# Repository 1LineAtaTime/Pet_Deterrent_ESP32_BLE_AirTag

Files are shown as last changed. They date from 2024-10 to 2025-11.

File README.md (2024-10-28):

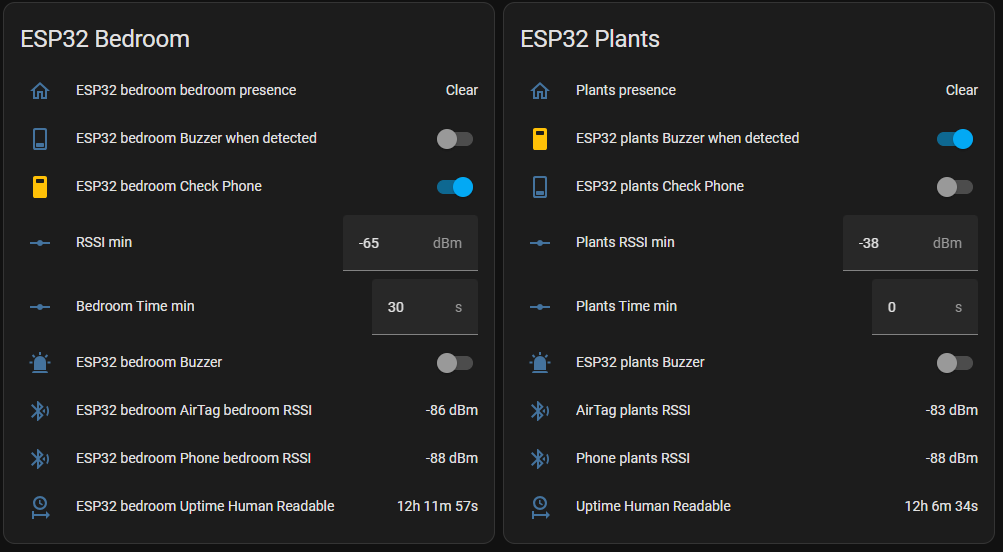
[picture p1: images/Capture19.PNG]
overview


# Introduction

Please note there are 2 different branches in this repo: this one uses ESPhome and Alexa_Media_Player instead to integrate with Home Assistant, Alexa, OTA, monitoring, etc. The other one is standalone with "Sinric Pro" to integrate with Alexa and OTA.

Pet Deterrent by using a Mini ESP32 with BLE scanning, WiFi, Alexa integration and OTA through ESPHome, Home Assistant and Alexa_Media_Player.

This program transforms an ESP32 into an AirTag detector (or any other BLE device) and pushes notifications to a dashboard in Home Assistant, which manages the OTAs and the Alexa integration.

There are a myriad of use cases for this device. I personally created it to know when my cats decide to start eating my plants or go into a room they are not supposed to be in. Both of my cats have an AirTag on their collar, in case one day they escape, so I can get an idea of what neighborhood they could be in. I then use these same air tags to detect if they are nearby. I have a spare iPhone I used to set them up on the Find My network, but then shut it off. The anti-stalker feature of the AirTag makes it advertise its presence every 2 seconds when they've been out of range of the parent phone for a while. Both the Address() and ManufacturerData() of the AirTag changes periodically, but we can extract the first few characters of the ManufacturerData() to identify it. More info on the Advertising Data can be found [here](https://adamcatley.com/AirTag.html).
> [!TIP]
> The anti-stalker feature now also makes the AirTag beep every few hours. I just opened it up and removed the diaphragm that amplifies the sound. There are plenty of videos online on how to do it without breaking your AirTag. While this doesn't completely turn off the sound, it makes the sound not noticeable, which is kind of important if your pet is going to be carrying it all the time. The anti-stalker feature only activates if it doesn't detect your iPhone for X number of hours. I use Android, so my iPhone is stored in a box turned off.

Other cases could be setting a trap door that only gets activated by a specific type of BLE device (e.g. backyard dog trap door), etc.

Since I did not want to have 3 different files to maintain for the 3 ESP32's I have around the house, I have tried to implement everything into one. 
In my case, I have 1 of the ESP32 in the bedroom, which will trigger the alarm if and only if my phone is not detected while the Air Tag is there, but the RSSI value is pretty laxed (-60, which in that room is approximately 6 feet). 
On the other hand, I do not need to check if my phone is nearby for the ESP32 boards I have next to the plants, which also has a pretty tight threshold (-38, about 4 inches away).

```
RAM:   [==        ]  16.5% (used 54216 bytes from 327680 bytes)
Flash: [=======   ]  74.5% (used 1366497 bytes from 1835008 bytes)
```
FYI, I had initially reduced the SPIFFS partition while leaving OTA intact with "board_build.partitions = min_spiffs.csv" in platformio.ini for the other branch, but the initialization of the ESP Home website formats the board differently, I believe.

# Instructions

1. Set up your board as you'd like. This is how mine looks.
    I am using this [Mini ESP32](https://www.aliexpress.us/item/3256806443469796.html), this [buzzer](https://www.ebay.com/itm/126428954898) and [this case](Archives/ESP32_wider_opening_for_USB.stl) with this [cover](Archives/ESP32_Top.stl).

    Please keep in mind this case is not mine. I watched a video on YouTube and downloaded it from a guy that made it there. I just cannot remember where I got it from! I've searched my history and still nothing. So if you happen to figure it out, let me know and I'll update the credits.

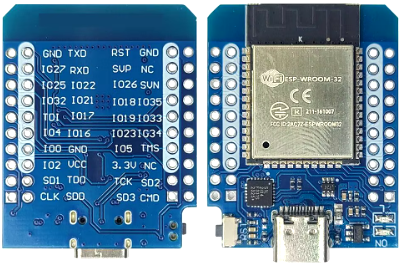
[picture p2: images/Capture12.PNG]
esp32
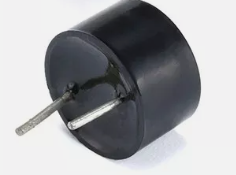
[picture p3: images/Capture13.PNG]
buzzer
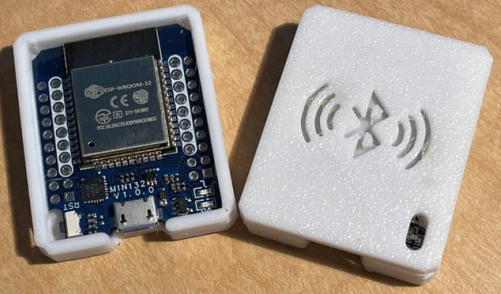
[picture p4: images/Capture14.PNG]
esp32 case
      

    You can use any service you want to print the case. I used JLCPCB.com as they had a great price for the material I wanted. Don't let the "3D-printed" part of it fool you into thinking it is not a solid case. It definitely is if you use SLA, and it won't break when you open and close it a million times while tinkering.

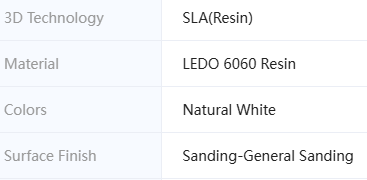
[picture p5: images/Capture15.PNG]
material type
    
    
    I soldered the buzzer between GPIO21 and GND, as they were perfectly spaced for the spacing between the buzzer legs. I used a tiny drill bit so the buzzer legs would fit snugly through the cover, and then soldered it with the cover in place, as it is a semi-permanent set up. You can always desolder the buzzer from the board if you want to repurpose it.
    Make sure to use the correct buzzer type, like the one I linked above. Otherwise it may not work, or you may fry your pin/board. My buzzer works at the ESP32-supplied voltage and does not need any additional components. You may want to modify this if you are looking for something way louder though.

2. Make sure to create a secrets.yaml file in the same folder as the .yaml file you are trying to compile with the contents shown below:
    ```
    # Your Wi-Fi SSID and password
    wifi_ssid: "your wifi ssid"
    wifi_password: "your password"

    ota_password: "whatever ota password you put in home assistant and your installation of ESPHome"
    api_password: "whatever api password you put in home assistant and your installation of ESPHome"
    ```

3. Add the lines below in your [homeassistant/config/configuration.yaml](Archives/configuration.yaml). This will create an input text box in Home Assistant that ESP Home will use as the RSSI threshold value. You can then tweak the value to your desired threshold from the Home Assistant dashboard without having to restart anything. Changes will happen in the blink of an eye! You can either add one of these for each ESP32 location you have, or use the same for all of them.
I do have a time_rssi_present to configure how long the devices need to be detected in order for the buzzer to go off. You can leave this at 0 seconds so it instantly alerts if they are detected. Please note that the location variable substitution from the ESPHome yaml file has to be at the beginning of the name of these input variables, so ESPHome can find them.
    ```
    input_number:
      bedroom_time_present:
        name: Bedroom Time min
        min: 0
        max: 300
        step: 1
        mode: box
        unit_of_measurement: s

      plants_time_present:
        name: Plants Time min
        min: 0
        max: 300
        step: 1
        mode: box
        unit_of_measurement: s

      bedroom_rssi_present:
        name: Bedroom RSSI min
        min: -120
        max: -20
        step: 1
        mode: box
        unit_of_measurement: dBm
      
      plants_rssi_present:
        name: Plants RSSI min
        min: -120
        max: -20
        step: 1
        mode: box
        unit_of_measurement: dBm
    ```
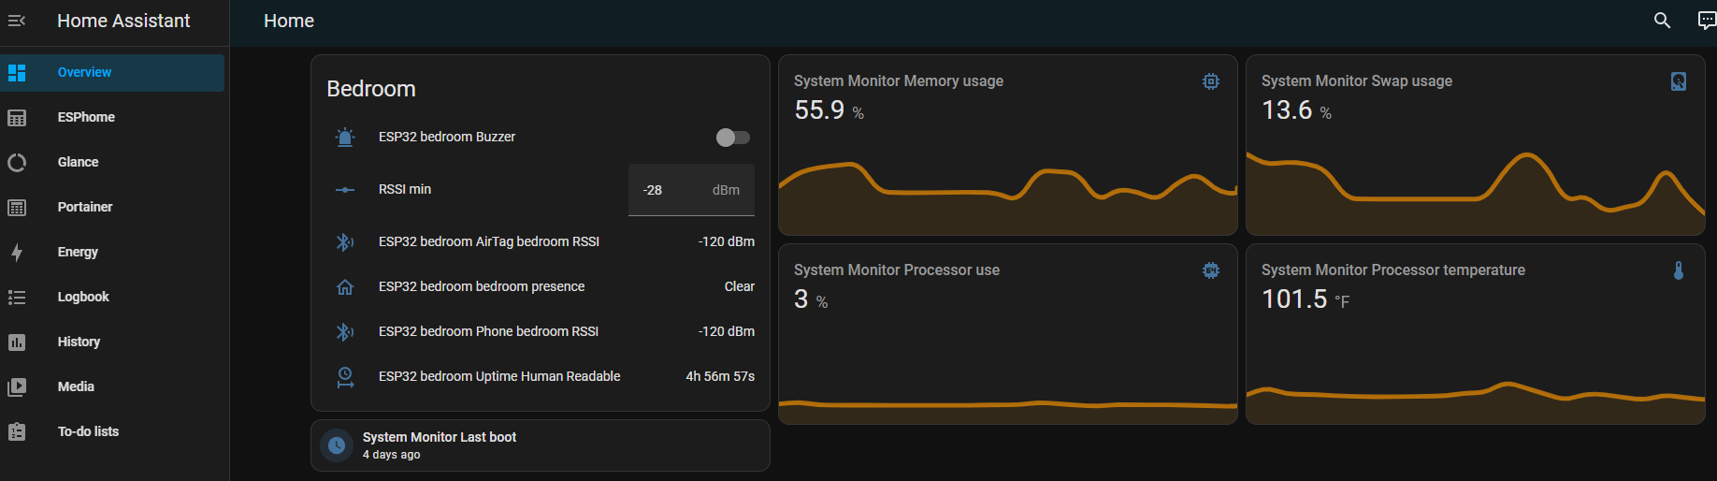
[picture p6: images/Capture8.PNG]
Screenshot of the Home Assistant dashboard with RSSI min threshold
    

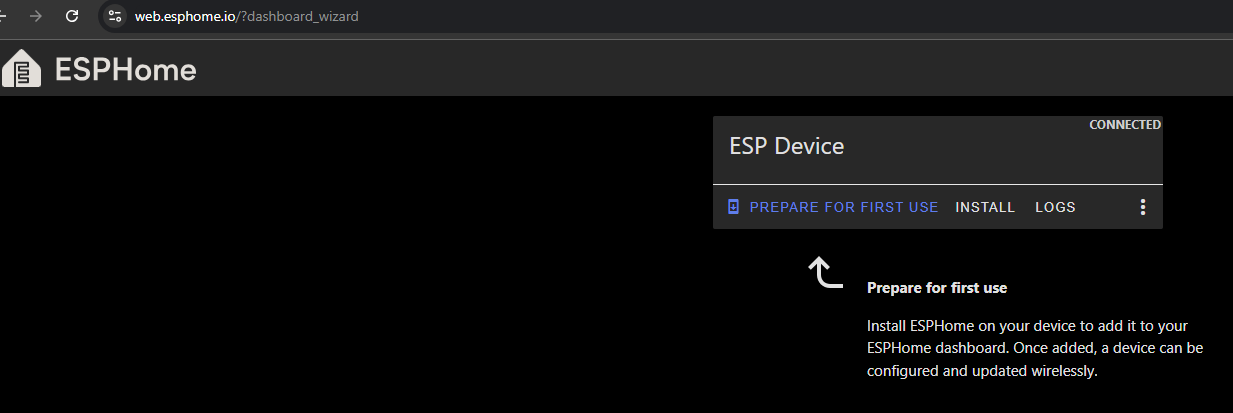
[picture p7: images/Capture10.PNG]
Screenshot of ESPHome Website
4. Go to the [ESPHome website](https://web.esphome.io/?dashboard_wizard) and connect your board. Then select "Prepare for first use" so the board gets configured correctly. 

5. To install ESPHome compiler locally in your computer:
    ```
    > pip3 install wheel
    > pip3 install esphome
    ```

6. To compile and upload ESPHome yaml file (my port is COM3, but you can use a different one or even OTA by adding its IP like shown below):
    ```
    > esphome run src\esp32-bedroom.yaml --device COM3
      ...or...
    > esphome run src\esp32-bedroom.yaml --device 10.0.0.195
    ```
> [!NOTE]
> If you are facing compilation errors after making changes, you may need to do a clean compilation by deleting the .esphome folder.

7. Now you can go to your ESPHome dashboard and add the device if it doesn't already show up in there. You can select new device if that makes it any easier. Another option is going to Home Assistant's Settings, Devices & Integrations, and then either Add Integration, or Configure device, if it has already found the ESPHome device.
    I also went ahead and added my secrets.yaml file to the secrets tab in this screen, in case I ever need to update things through the browser. 
    I have also noticed that it may be necessary to have different yaml file names to avoid conflicts, but once you create a new device you can just use the new name as needed.
    ESP Home screenshot

8. [Alexa_Media_Player](https://github.com/alandtse/alexa_media_player/releases/download/v4.13.5/alexa_media.zip) (found in Archives if needed). 
    This is supposed to be saved in the homeassistant/config/custom_components/alexa_media folder. I am using v4.13.5, but feel free to download a different one from the official repository.
    For more details about how to integrate Alexa_Media_Player just watch [this awesome video](https://www.youtube.com/watch?v=lZpcyu9rnXo) and check out [his GitHub repo](https://github.com/Steven-D-Morgan/Morgans_Modifications/tree/main).
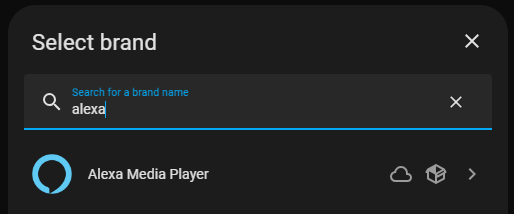
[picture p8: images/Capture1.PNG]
    
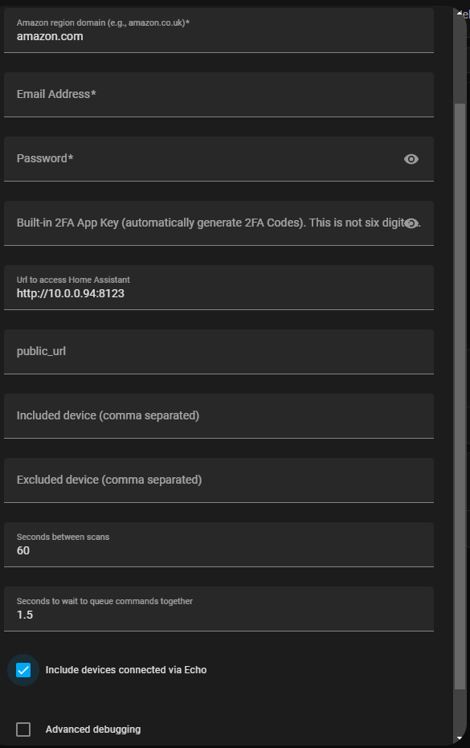
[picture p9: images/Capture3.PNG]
    
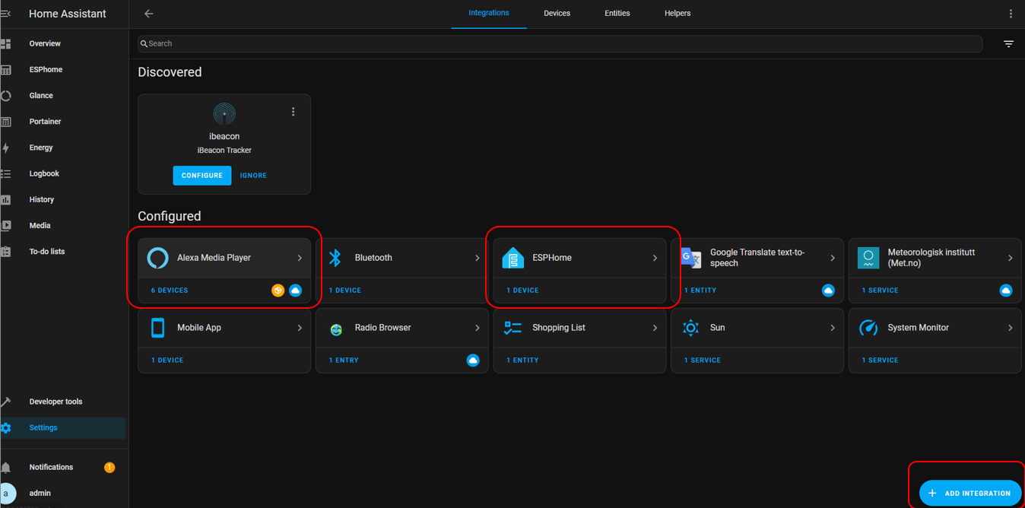
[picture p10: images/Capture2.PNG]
    

9. Now go to the Home Assistant Settings menu, Automations & Scenes, and Create a New Automation to announce in your Alexa device when the buzzer pin state changes to on.
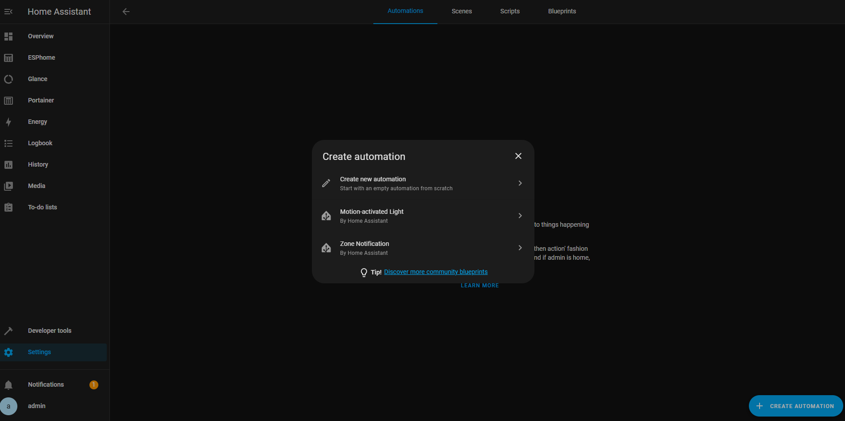
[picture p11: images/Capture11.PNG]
    
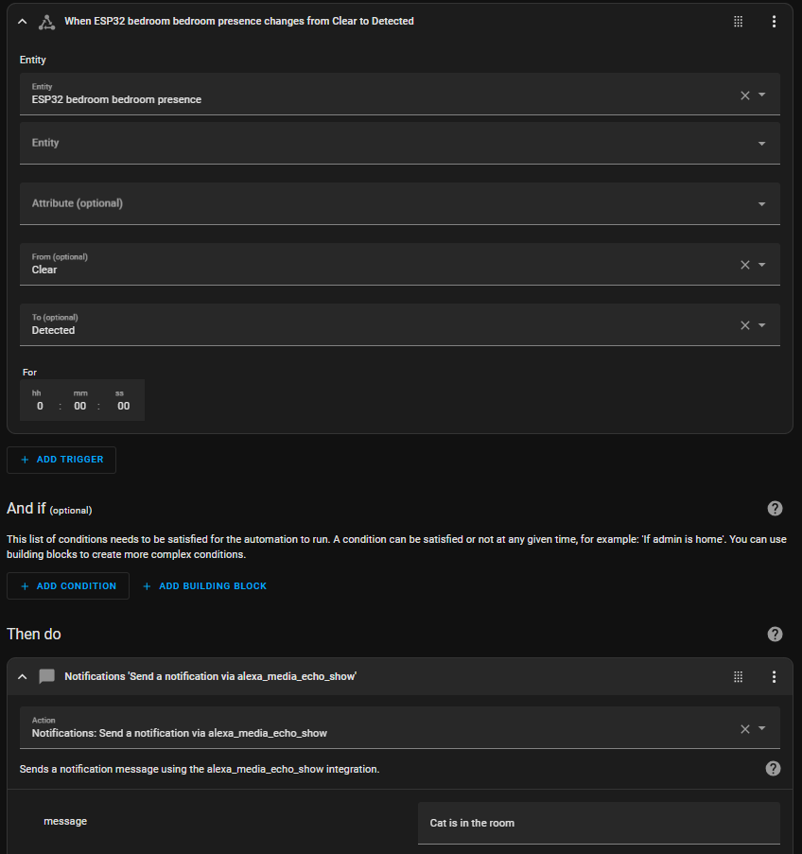
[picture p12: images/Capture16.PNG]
    

10. In Home Assistant, toggle the "Check Phone" switch as needed for your specific board and setup. I have only 1 where it checks for my phone (as the RSSI threshold is quite high at -70), but the other 2 boards I have around the house do not need to check for my phone, since they are right on the plants (with an RSSI threshold of like -30, which means the AirTag has to be almost on top of it to trigger the buzzer). If you are going to be checking for your phone's RSSI, make sure to update the line in the esp32-bedroom.yaml prior to compilation. You can get the phone's uuid from the Home Assistant Android/iPhone app, Settings, Companion App, Manage Sensors, Bluetooth Sensors, BLE Transmitter.

11. Feel free to set up your Home Assistant dashboard however you like it. In my case, I just brought it all to the main Overview screen and show it for each location. If it does not show up, you can try adjusting the Area in Settings, Devices & Entities, Entities, or directly editing the dasbhoard in the Overview screen.
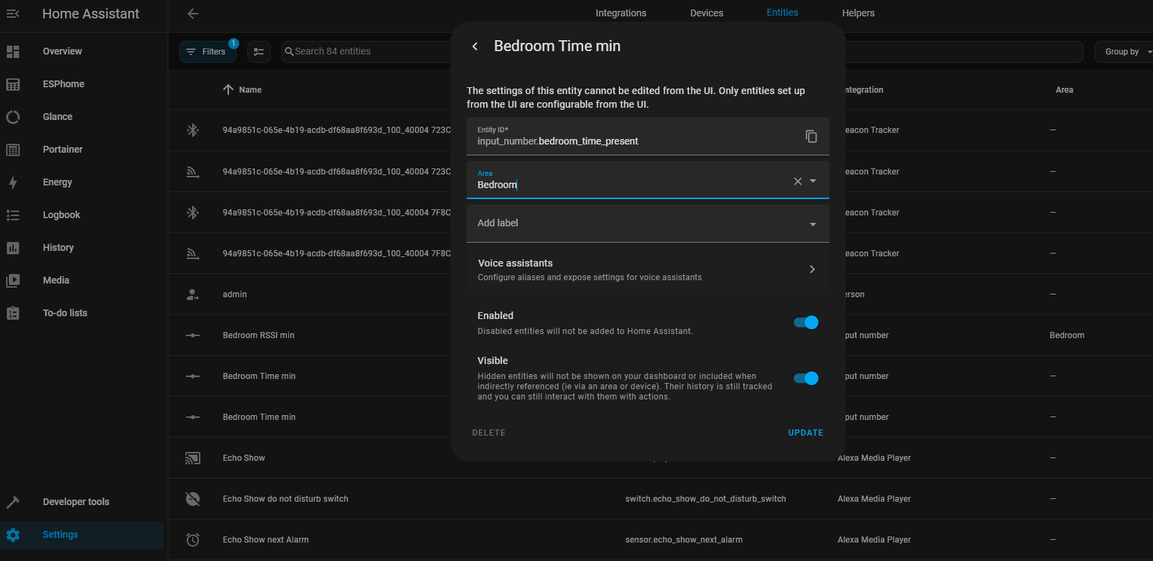
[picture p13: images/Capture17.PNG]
image of Area
    
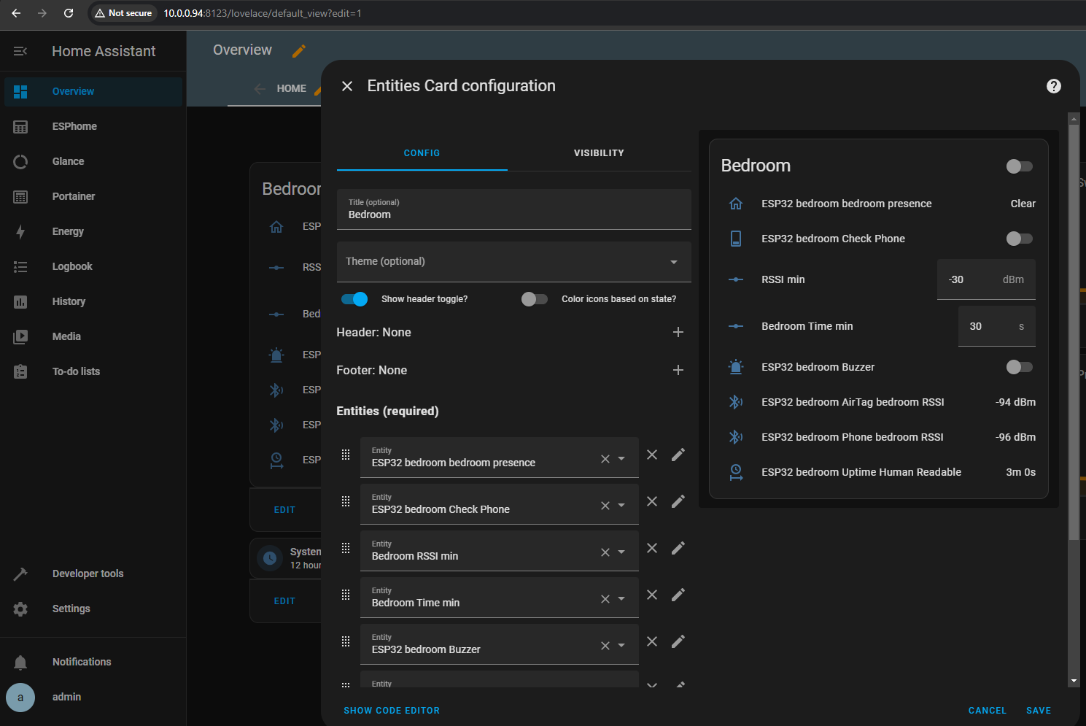
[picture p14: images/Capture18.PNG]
image of Area
    

> [!TIP]
> It is recommended to use the ESP Home YAML language extension on Visual Studio when editing .yaml files. It makes it easier to avoid mistakes. Makes it easy to read, and it describes options by hovering over them.
> The Remote - SSH Visual Studio extension also makes it easy to log in to the Raspberry Pi, edit files and execute shell commands as needed.

> [!NOTE]
> For reference, I am running this on a Raspberry Pi 3B (only 1GB of RAM!). Main OS flashed is the official Raspbian (server edition to save on resources). Then Docker with Portainer as the GUI. Inside Docker, I have 4 containers: Portainer, ESP Home, Home Assistant and Glance (although this one I am currently not using, so I have it disabled).
> Overall RAM usage is ~50%, and SWAP is ~20% (increased to 1GB total).
> 
> Using esp-idf instead of the Arduino framework to save on the ESP32 resources. The main reason for running the compilation and upload of the ESP Home binary for the ESP32 on my local computer is to use Visual Studio, GitHub code control and speed up the tweaking process, since my Raspberry Pi cannot keep up with all of these.
> 
> I have also saved my [docker-compose.yaml](Archives/docker-compose.yaml) and [homeassistant/config/configuration.yaml](Archives/configuration.yaml) files in the Archives folder in case it helps anyone trying to set up their system like mine.
> 
> There are also a few more pictures in the images folder. Feel free to go through them to get a better idea of my setup if needed.

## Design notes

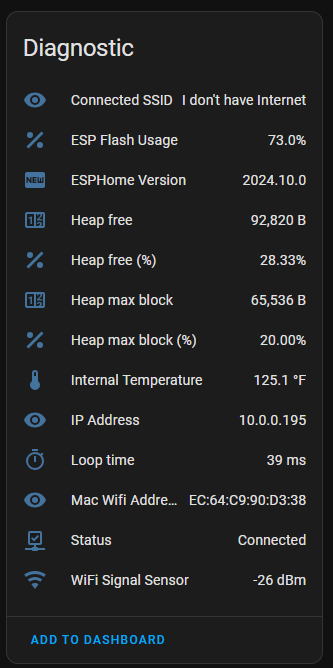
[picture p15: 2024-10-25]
images/Capture6.PNG

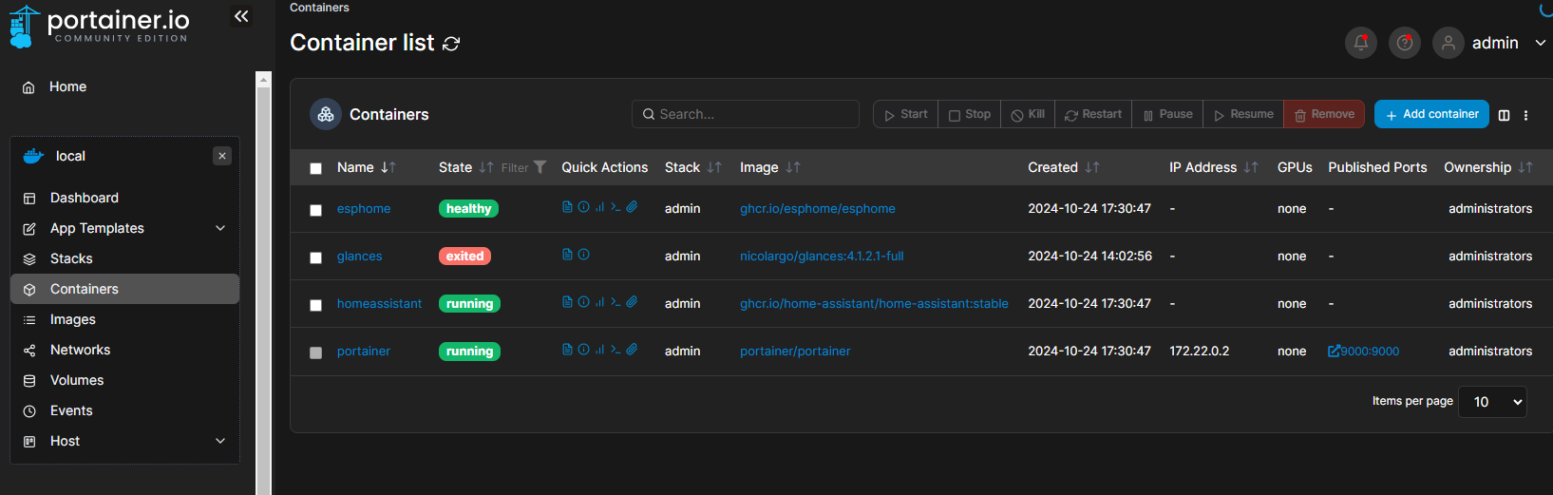
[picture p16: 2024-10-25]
images/Capture4.PNG

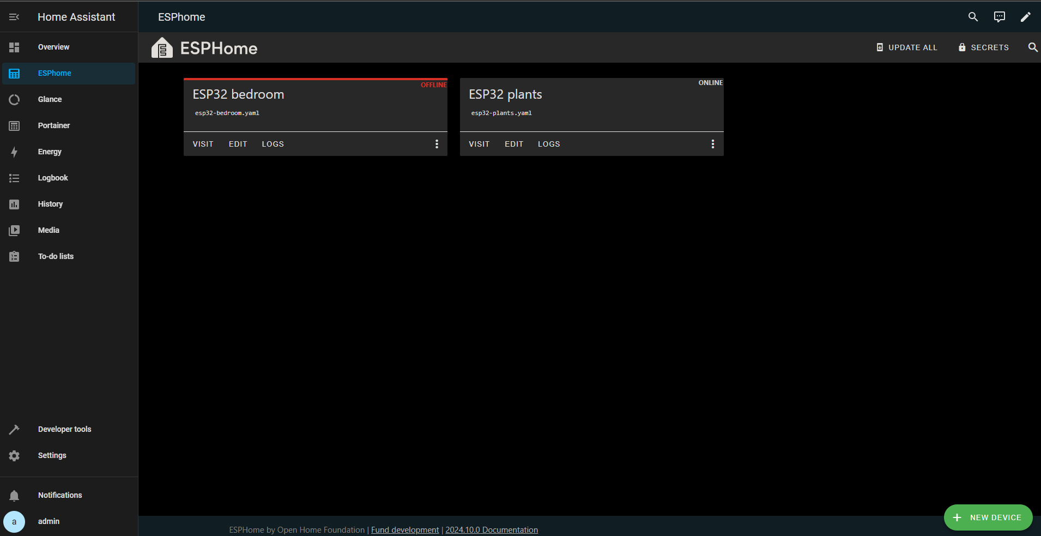
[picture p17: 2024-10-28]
images/Capture20.PNG

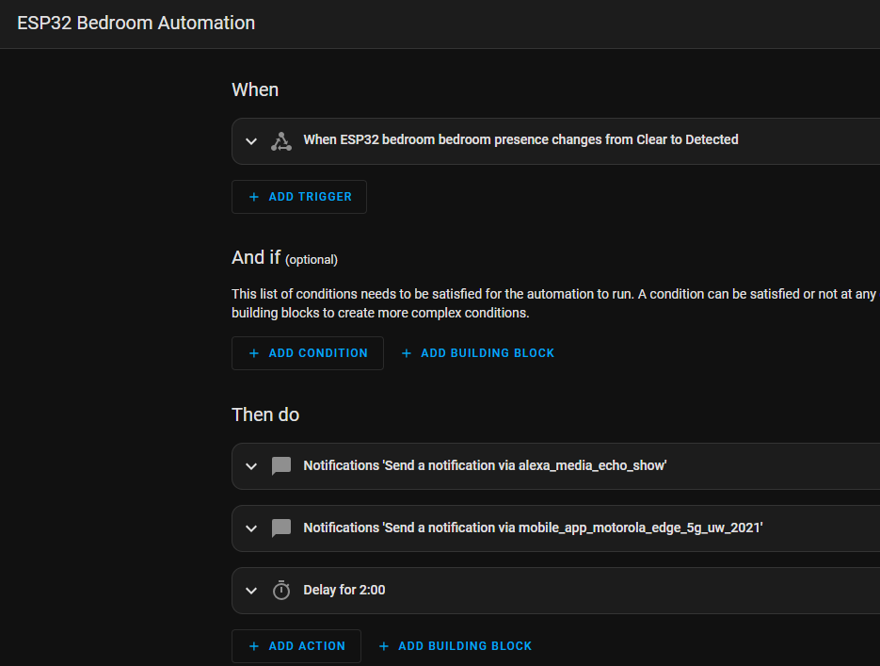
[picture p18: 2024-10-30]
images/Capture21.PNG

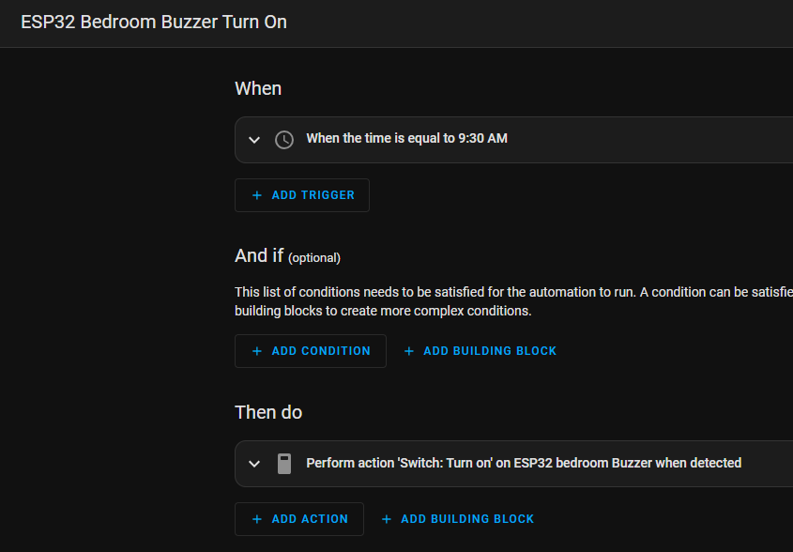
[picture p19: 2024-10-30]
images/Capture22.PNG

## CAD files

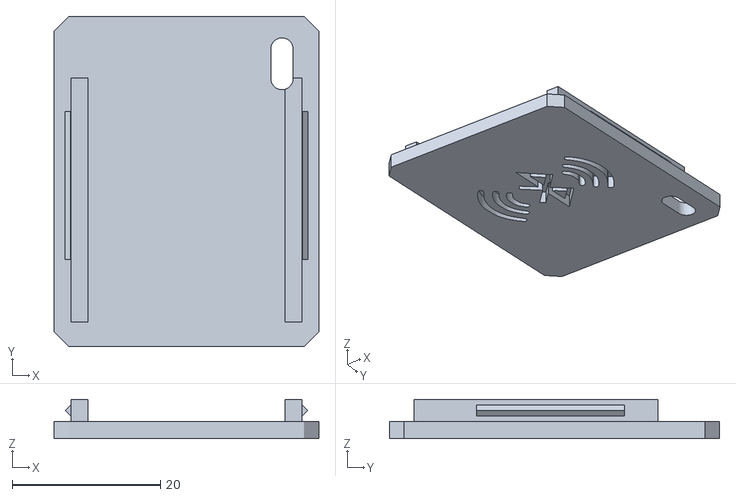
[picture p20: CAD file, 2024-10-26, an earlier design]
Archives/ESP32_Top.stl
35.8 x 44.6 x 5.30

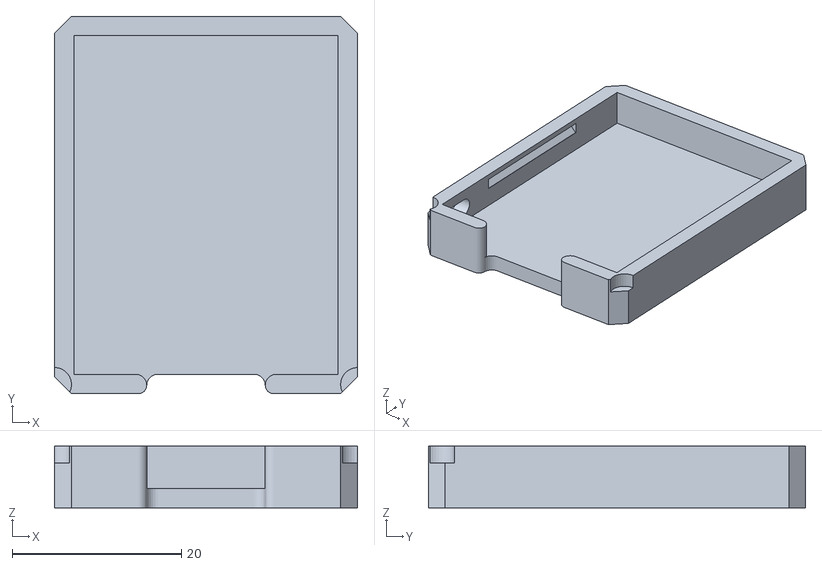
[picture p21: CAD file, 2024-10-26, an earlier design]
Archives/ESP32_wider_opening_for_USB.stl
35.8 x 44.6 x 7.30

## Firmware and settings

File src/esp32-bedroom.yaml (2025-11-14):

# credits for initial template to https://github.com/homeautomatorza/esphome/blob/main/Lets_build_a_room_sensor/Part%200/code.yaml
# credits for part of the BLE section to https://github.com/dalehumby/ESPHome-Apple-Watch-detection
# credits for ESP32 internal sensor data to https://github.com/SeByDocKy/pvbrain2/
################################################################################
# Substitution Variables
################################################################################
substitutions:
  sketchVersion: "1.5"
  location: bedroom # bedroom or plants
  device_internal_name: esp32${location}
  device_wifi_name: esp32_${location}_wifi
  device_friendly_name: ESP32 ${location}
  device_sampling_time: 60s
  phone_uuid: "0x004C.02.15.94.A9.85.1C.06.5E.4B.19.AC.DB.DF.68.AA.8F.69.3D.00.64.9C.44.C5" #advertised name in BLE from Home Assistant App
  phone_uuid_length: (23)
  airtag_uuid: "0x004C.12.19." # it used to be .40 .50 or .90 before # Begining of Manufacturer Code for AirTags
  airtag_uuid_length: (27)
  buzzer_pin: GPIO21
  led_pin: GPIO2

################################################################################
# Globals
################################################################################
globals: 
  - id: wifi_connection
    type: bool
    restore_value: no
    initial_value: "false"

  - id: rssi_threshold_value # minimum RSSI value the devices need to have to be detected and alerted
    type: float
    initial_value: '-26.0'

  - id: time_threshold_value # minimum amount of time the device needs to be detected for in order to alert
    type: int
    initial_value: '0'

  - id: airtag_max_rssi_scanned
    type: int
    initial_value: '-120'

  - id: phone_max_rssi_scanned
    type: int
    initial_value: '-120'

  - id: last_event_time
    type: unsigned long
    restore_value: no
    initial_value: '0'

################################################################################
# Board Configuration
################################################################################
esphome:
  name: ${device_internal_name}
  friendly_name: ${device_friendly_name}
  platformio_options:
    build_flags: 
      - -Wno-maybe-uninitialized

esp32:
  board: esp32dev
  framework:
    type: esp-idf # 70% Flash usage vs 90% with arduino

################################################################################
# Enable logging
################################################################################
logger:

################################################################################
# Enable debugging features
################################################################################
debug:
  update_interval: ${device_sampling_time}

################################################################################
# Enable Home Assistant API
################################################################################
api:
  reboot_timeout: 15min #default
  encryption:
    key: !secret api_password

################################################################################
# OTA
################################################################################
ota:
  - platform: esphome
    password: !secret ota_password

################################################################################
# WiFi
################################################################################
wifi:
  reboot_timeout: 15min #default
  networks:
    - ssid: !secret wifi_ssid
      password: !secret wifi_password
      
  # Enable fallback hotspot (captive portal) in case wifi connection fails
  ap:
    ssid: ${device_wifi_name}
    password: !secret wifi_password

captive_portal:

################################################################################
# Web Server --> using it to debug things as the RaspPI3B Home Assistant has been crashing lately
################################################################################
web_server:
  port: 80
  version: 2
  include_internal: true
  local: true

################################################################################
# Time
################################################################################
time:
  - platform: homeassistant
    id: homeassistant_time
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

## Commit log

2024-10-26 cleaned up code + activated buzzer
    [esp32-bedroom.yaml]
2024-10-26 added hardware details to ReadMe
    [ESP32_Top.stl, ESP32_wider_opening_for_USB.stl]
2024-10-27 Details for ReadMe + Fixed Time Threshold var
    [configuration.yaml, esp32-bedroom.yaml]
2024-10-28 Added versions + buzzer option
    [esp32-bedroom.yaml]
2024-10-30 fixed time threshold >= 50
    [esp32-bedroom.yaml]
2024-11-03 changed reboot time without Home Assistant
    [esp32-bedroom.yaml]
2025-11-04 fixed typo on time variable and added 2 new locs
    [esp32-kitchen-1.yaml, esp32-kitchen-2.yaml, esp32-plants.yaml]
